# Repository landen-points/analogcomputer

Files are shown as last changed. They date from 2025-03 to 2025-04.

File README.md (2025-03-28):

# analog computer
This project involves designing and building a simple analog computer capable of solving calculus-based
operations such as integration, differentiation, and summation using op-amp-based circuits to a proof-of-
concept level accuracy. The core components will include TL082 dual op-amps, a variety of passive
components (resistors, capacitors), and voltage regulators.

Instead of using a traditional PCB, the final prototype will be made using paper circuits. Paper circuits are
more DIY friendly, and will be open source. I am also interested in incorporating non-traditional
fabrication techniques as a proof of concept for analog computing. This approach aims to provide a low-
cost, flexible, and rapidly prototyped alternative to standard PCBs, as there is no lead time for PCB
ordering.

I gained inspiration from reading the Art of Electronics Second Edition (Horowitz and Hill) chapter on
op-amp designs for calculus functions (chapter 4), and further research into devices such as the Comdyna
GP-6.

The circuits used in the analog computer are separated by module, so a build can incorporate how ever many of each are desired.

To build a computer of your own:
  1. Print the paper circuit modules located in ./papercircuits/pdf to US letter size (8.5x11in) paper
  2. Cut the modules accordingly
  3. Poke holes through lead locations and place components in. Suggested component values are printed on the paper circuit PDFs
  4. Solder them together, using legs or jumpers. Be creative with it
  5. To mount to a panel, I use M3 screws driven directly through the paper circuit and into a wood panel. Leave them as bare paper circuits if desired
  6. Connect a ±12V supply

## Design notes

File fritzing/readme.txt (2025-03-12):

These were the original paper circuit designs made with Fritzing.
I used to use Fritzing to create simple paper circuit layouts, but the software has since become limiting and my own install stopped working anyways.
These designs are finished and should work, I however have not tested them.

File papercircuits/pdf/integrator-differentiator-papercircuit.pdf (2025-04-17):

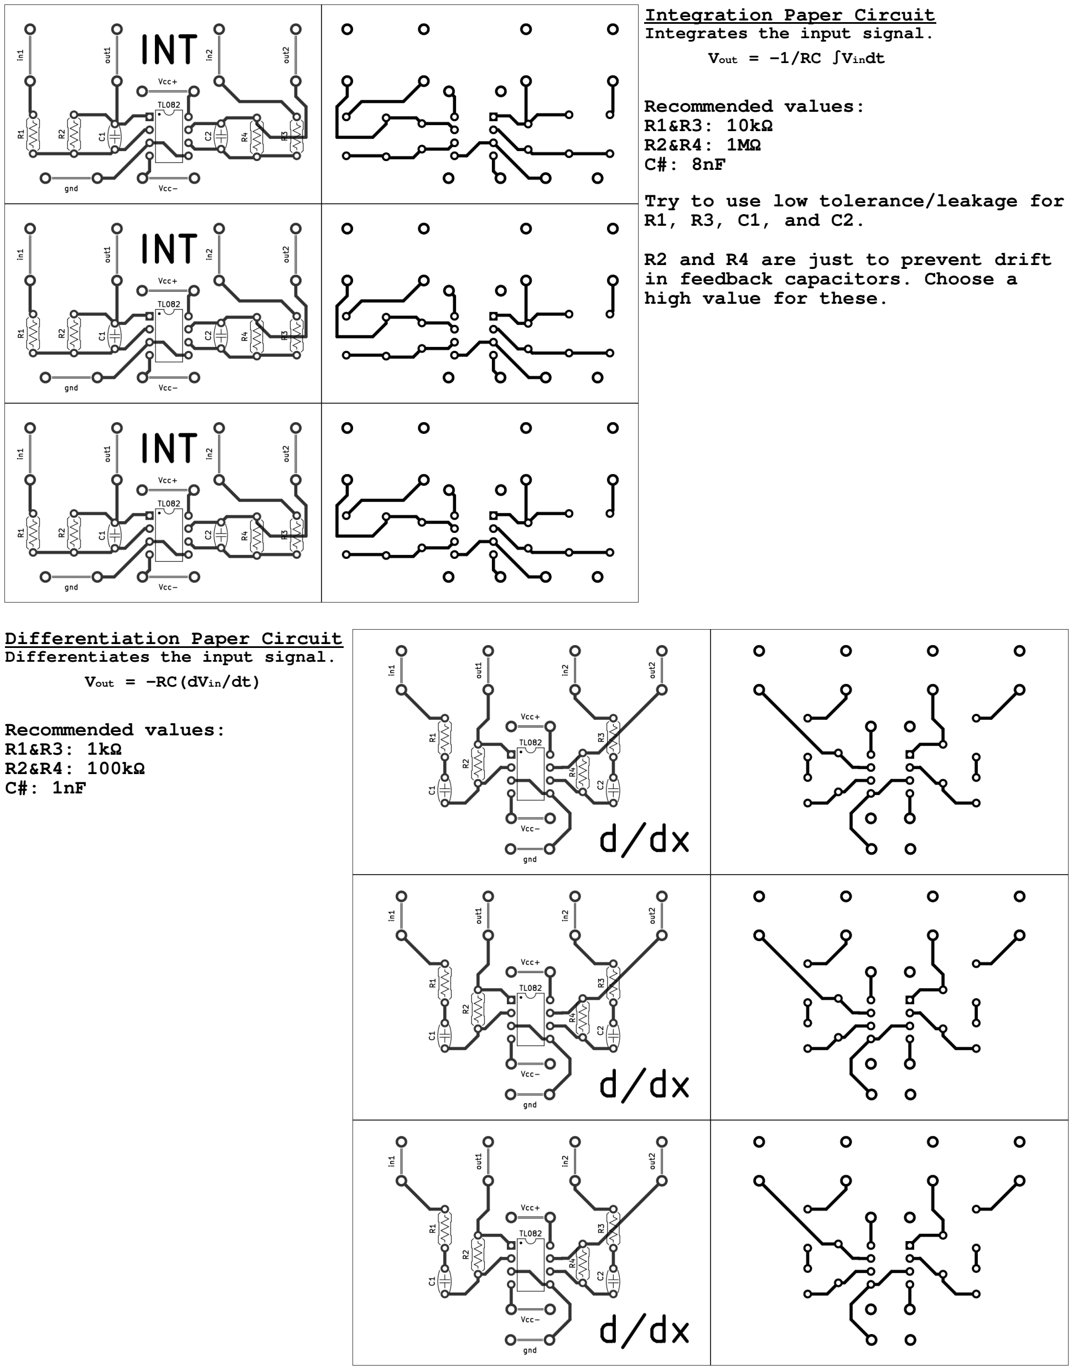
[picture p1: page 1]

Differentiation Paper Circuit
Differentiates the input signal. Vout = -RC(dVin/dt)

Recommended values:
R1&R3: 1kΩ
R2&R4: 100kΩ
C#: 1nF

Integration Paper Circuit
Integrates the input signal. Vout = -1/RC ∫Vindt

Recommended values:
R1&R3: 10kΩ
R2&R4: 1MΩ
C#: 8nF

Try to use low tolerance/leakage for R1, R3, C1, and C2.

R2 and R4 are just to prevent drift in feedback capacitors. Choose a high value for these.

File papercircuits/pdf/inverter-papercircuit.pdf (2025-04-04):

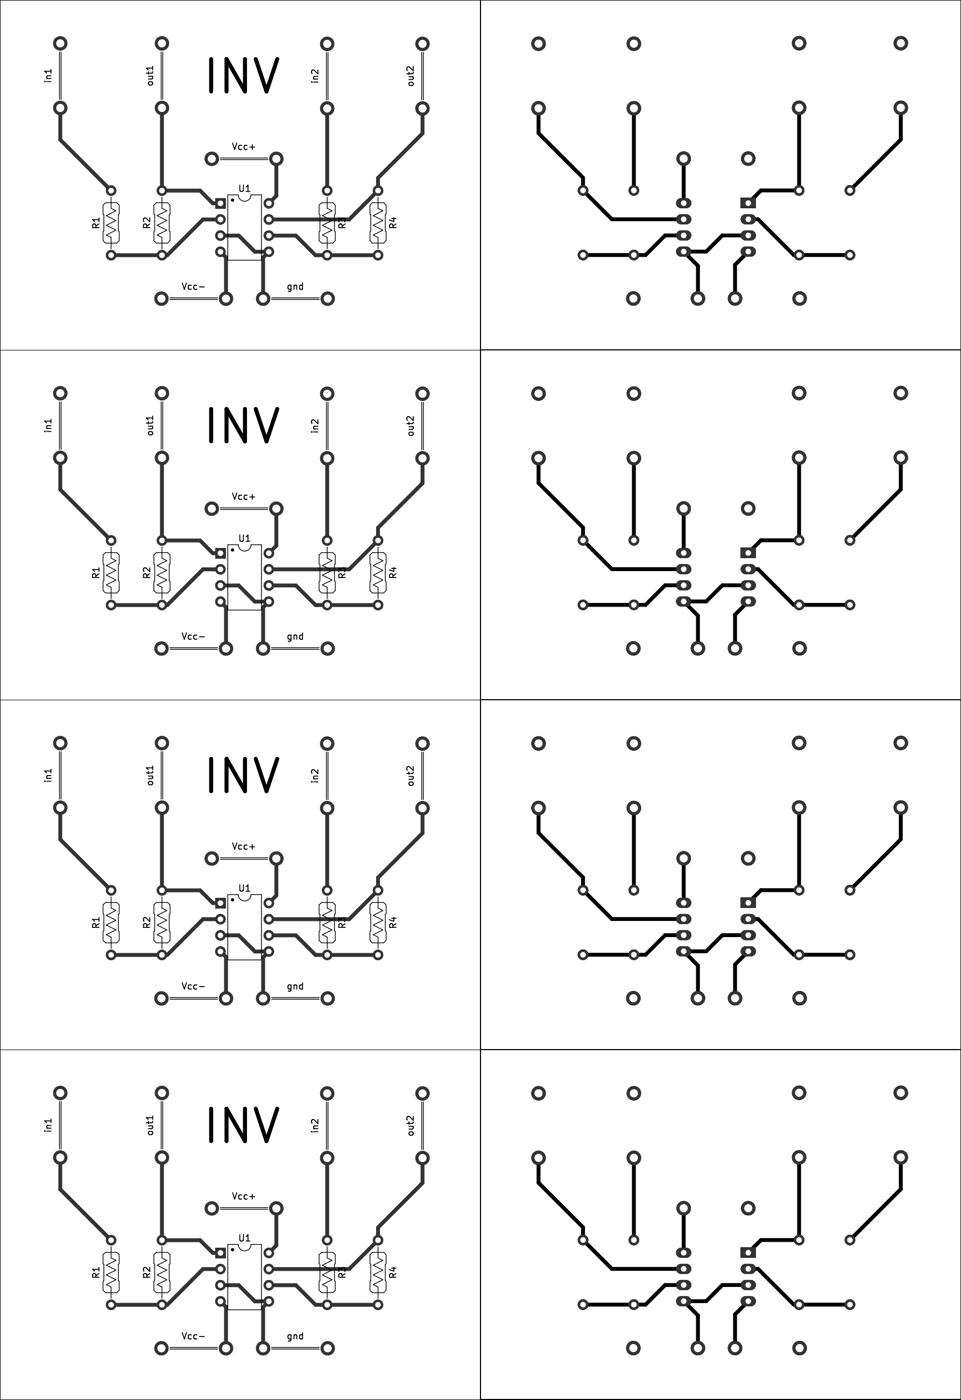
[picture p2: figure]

Inverter Paper Circuit
Inverts the input signal.

Vout = -Vin

Recommended values:
R#: 10kΩ

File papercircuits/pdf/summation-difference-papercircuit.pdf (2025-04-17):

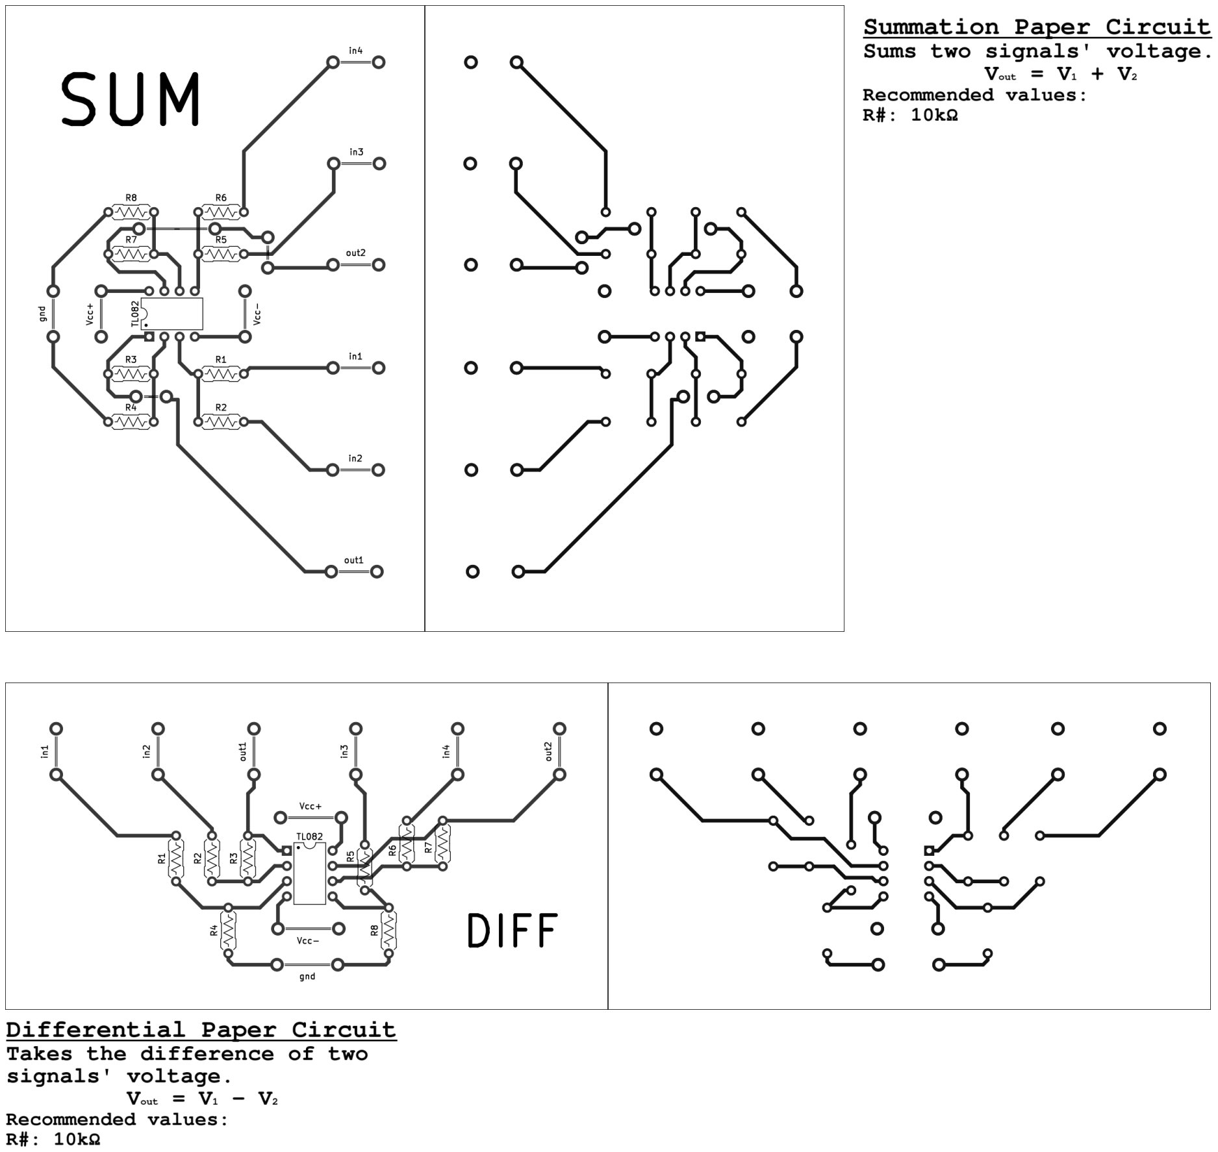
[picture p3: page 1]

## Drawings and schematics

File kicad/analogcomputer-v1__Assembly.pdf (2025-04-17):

# INT

# SUM

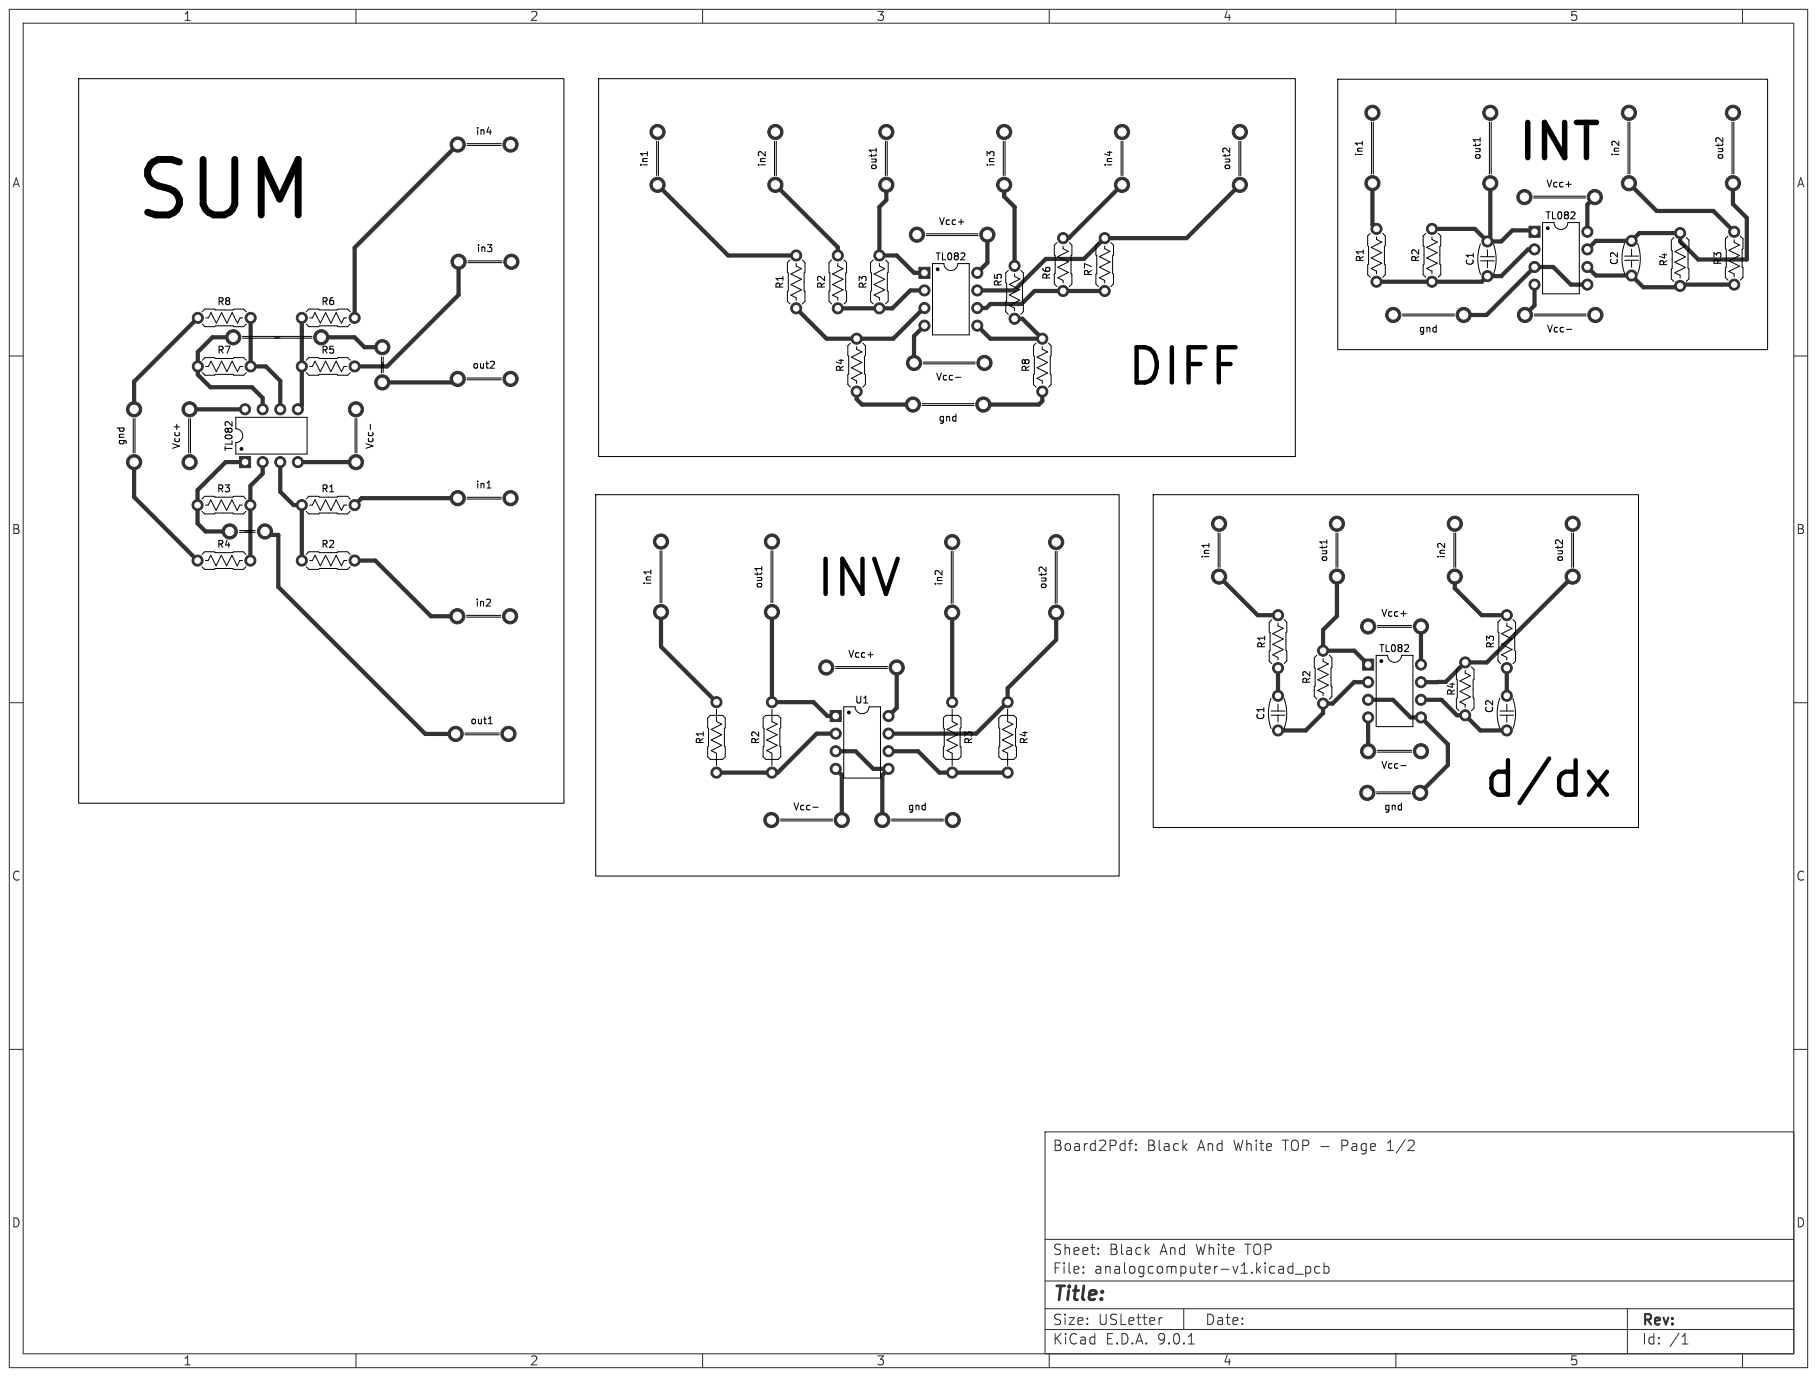
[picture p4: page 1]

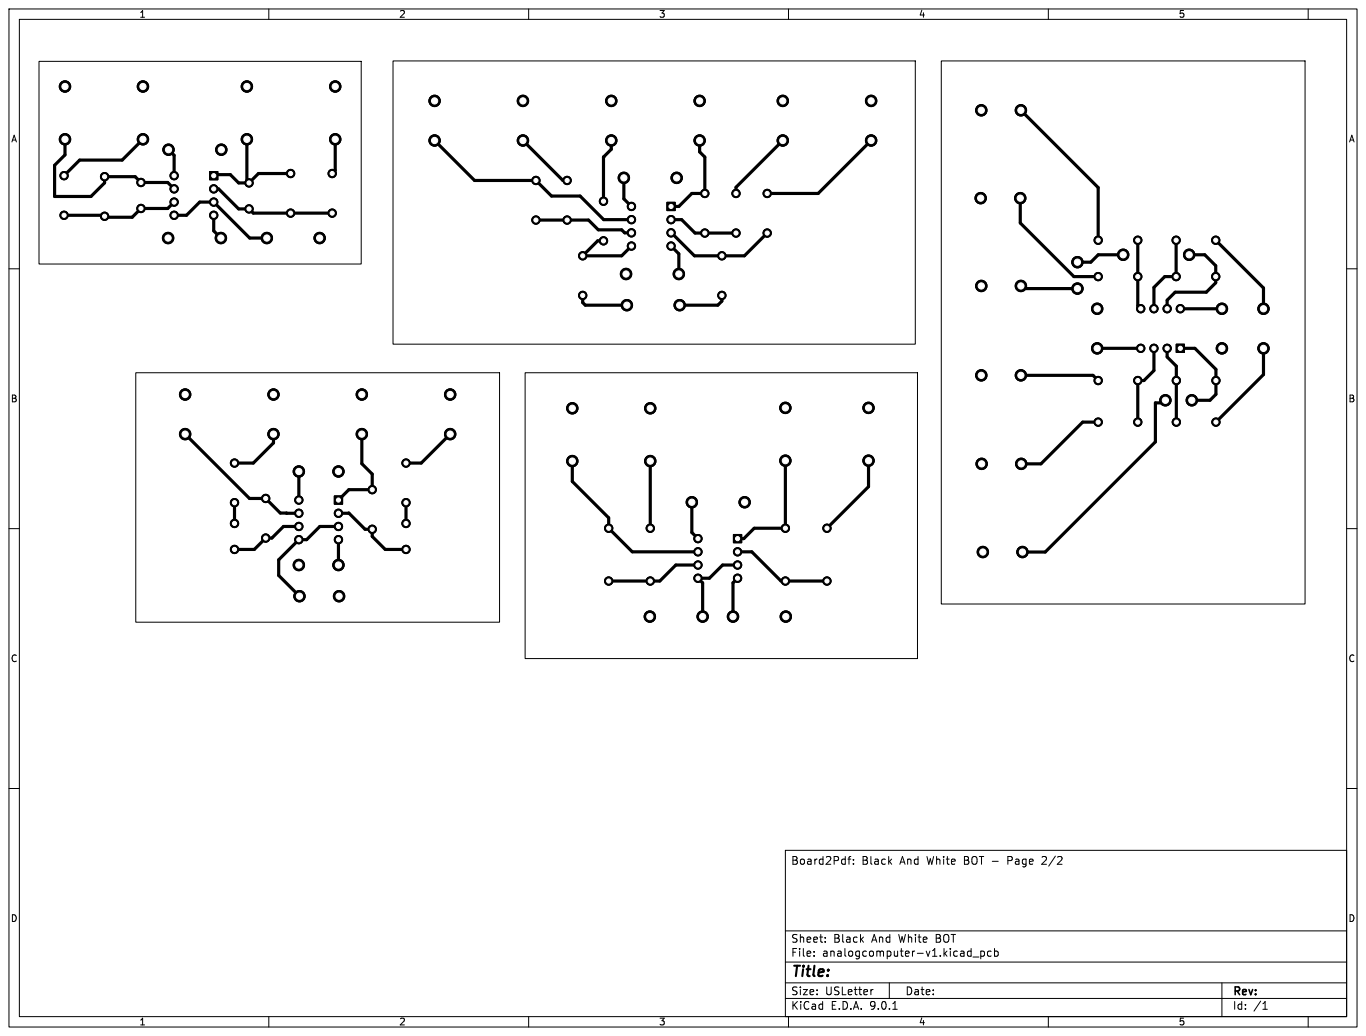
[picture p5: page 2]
D Date: KiCad; E.D.A. 9.0.1 Size: USLetter; Rev:; Id: /1 Title: File: analogcomputer-v1.kicad_pcb Sheet: Black; And; White; BOT Board2Pdf:; Black; BOT -; Page 2/2

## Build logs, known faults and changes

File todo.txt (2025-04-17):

±5V out from ±12V (±3.3V?)
Breadboard test d/dx circuit
Solder all circuits
  sum, diff, int, d/dx
Test all circuits
Panel design and drilling
Slideshow presentation

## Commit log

2025-03-11 add fritzing files
    [differential.fzz, integrator.fzz, sum.fzz]
2025-03-11 Create kicad folder
2025-03-11 add integrator kicad files
    [integrator.kicad_pcb, integrator.kicad_sch]
2025-03-11 add sum kicad files
    [sum.kicad_pcb, sum.kicad_sch]
2025-03-12 new sum and diff circuit layouts.
2025-03-12 add differential kicad folder
2025-03-12 differential kicad files
    [differential.kicad_pcb, differential.kicad_sch]
2025-03-14 integration and differentiation paper circuits
2025-03-26 corrected input capacitor value
    [differentiator.kicad_sch]
2025-03-28 unified project files
    [analogcomputer-v1.kicad_pcb, analogcomputer-v1.kicad_sch]
2025-03-28 inverter paper circuit
2025-04-04 updated with unified footprints
2025-04-04 updated sum circuit with wider output spacing
2025-04-04 updated sum with larger output spacing
    [analogcomputer-v1.kicad_pcb]
2025-04-17 updated differentiation circuit and spacing
    Spacing of ins/outs, added input resistor to differentiation circuit.
    [analogcomputer-v1.kicad_pcb, analogcomputer-v1.kicad_sch]
